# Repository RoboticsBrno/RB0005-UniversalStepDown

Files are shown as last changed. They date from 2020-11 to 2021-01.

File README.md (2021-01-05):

# RB0005 – Universal Stepdown

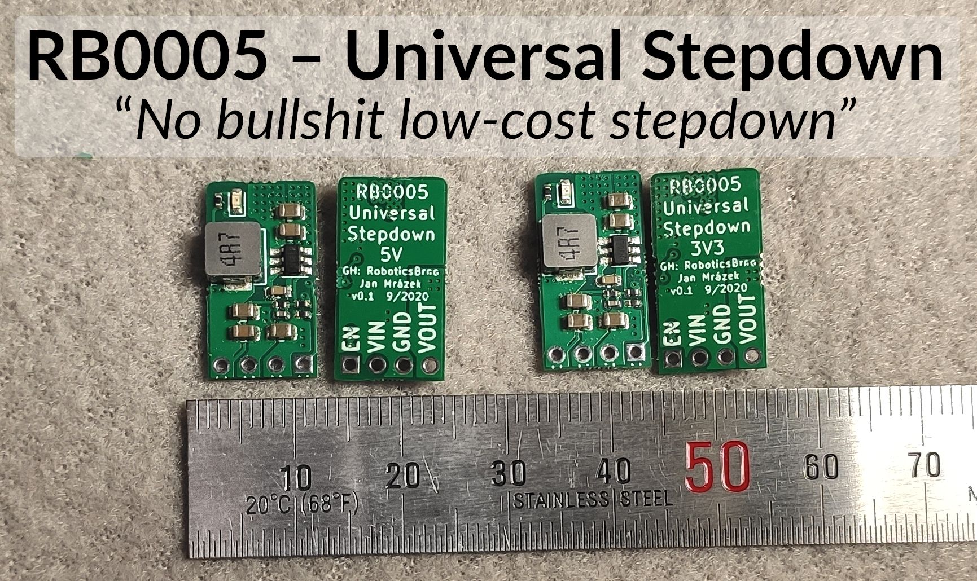
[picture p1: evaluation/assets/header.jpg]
StepDown photo




Most of our projects at RoboticsBrno are powered either by Li-ion cells or 12V
power sources. However, most of our servos and boards require either 5V or 3V3
power source.

We used to buy cheap stepdown modules from Aliexpress to do the job. They are
inexpensive but their performance is questionable. Also, it is always a
surprise what you get in the envelope – some batches of them operate better,
some of them worse. One day, we decided to stop wasting our time with
poor-performing modules and we designed our own custom module – the RB0005
Universal Stepdown.

It is a simple and low-cost design based on the
[SY8105](https://file.remont-aud.net/baza/dc_dc/data/SY8105.pdf). And it gets
the job done – see the evaluation of our design below. You can also look at our
design on the [project
repository](https://github.com/RoboticsBrno/RB0005-UniversalStepDown).

## What does the module offer?

- there are two versions – 5V and 3.3V fixed output
- input voltage up to 18 V
- continuous load: 3 A (without cooling)/4 A (with cooling)
- pin compatible with 7805 linear voltage regulator and most of the Chinese modules
- has an enable pin (pull low to disable the module)
- small factor 10.5×19.5 mm
- low price: ~3 USD
- you know what to expect – we provide measurements of the module performance
    - **see the performance of [the 5V version](https://roboticsbrno.github.io/RB0005-UniversalStepDown/eval5v/index.html)**
    - **see the performance of [the 3V3 version](https://roboticsbrno.github.io/RB0005-UniversalStepDown/eval3v/index.html)**
    - **see the performance of [the 5V version v2](https://roboticsbrno.github.io/RB0005-UniversalStepDown/eval5v_v2)**

## What we do not provide?

- high-end, precision solution
    - we do not focus on incredibly high module efficiency
    - we do not focus on being low-noise

## FAQ

#### Why the "RB0005" prefix?

To quickly distinguish our projects at
[RoboticsBrno](https://github.com/RoboticsBrno/), e.g., when ordering, we
decided to give a each project a unique code.

#### Why is there no adjustable version?

We aim for usability. Usually, you need to lower your voltage to 5 V (servos) or
3.3 V (powering MCU) in DIY robotics. Having an adjustable version increases
the chances of misconfiguration.

#### Why should I use your module instead of $1 module from Aliexpress?

Well, it depends on your needs. If you need a certain level of reliability, it
might be beneficial to know what to expect from your device. With our stepdown,
you know it: see [evaluation of the 5V
version](https://roboticsbrno.github.io/RB0005-UniversalStepDown/eval5v/index.html)
or the [the 3V3
version](https://roboticsbrno.github.io/RB0005-UniversalStepDown/eval3v/index.html).
You could buy a module from Aliexpress and measure it by yourself. However, that
is laborious and you cannot be sure that you will get the same-performing module
when you order it again.

## Licence

[RB0005 – Universal
Stepdown](https://roboticsbrno.github.io/RB0005-UniversalStepDown/) by [Jan
Mrázek](https://honzamrazek.cz) is licensed under [CC BY-NC-SA
4.0 ](https://creativecommons.org/licenses/by-nc-sa/4.0).

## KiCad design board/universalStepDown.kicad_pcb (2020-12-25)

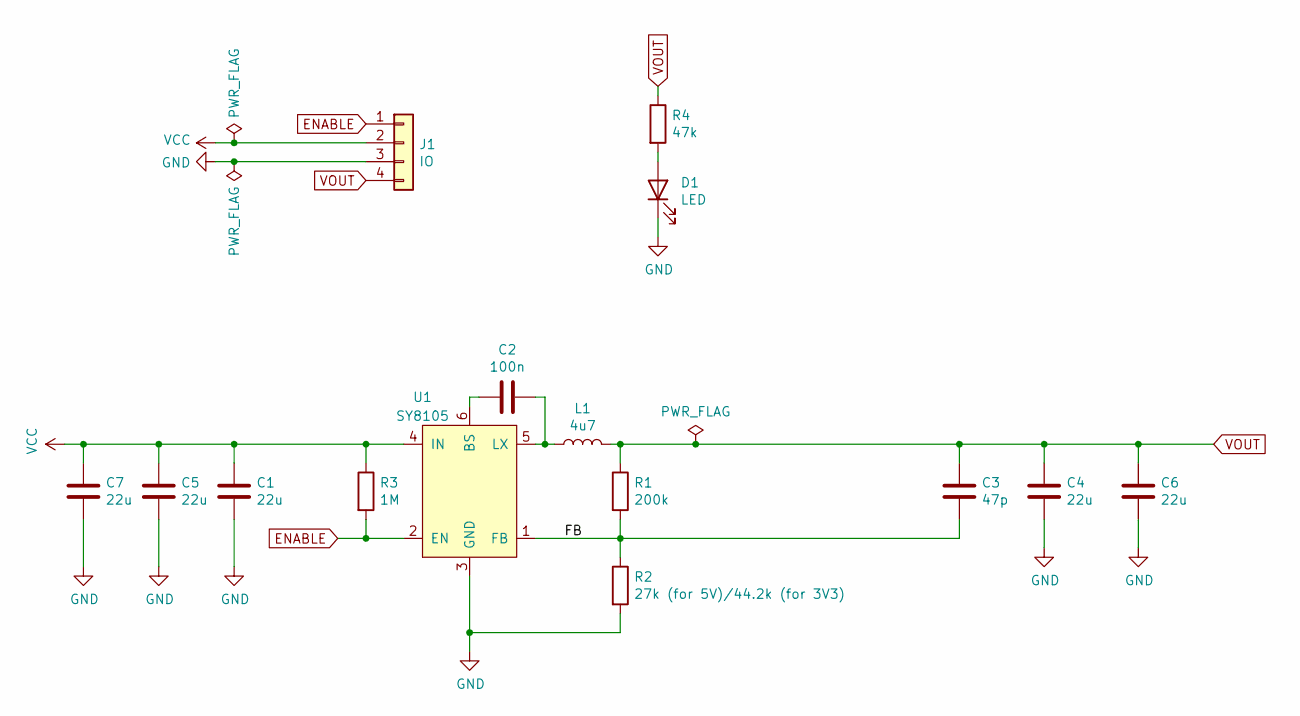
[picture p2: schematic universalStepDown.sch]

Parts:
C1, C4, C5, C6, C7: 22u; C_0805_2012Metric; LCSC C45783
C2: 100n; C_0603_1608Metric; LCSC C14663
C3: 47p; C_0402_1005Metric; LCSC C1567
D1: LED; LED_0603_1608Metric; LCSC C2286
J1: IO; PinHeader_1x04_P2.54mm_Horizontal
L1: 4u7; MWSA0503S; LCSC C408410
R1: 200k; R_0402_1005Metric; LCSC C25764
R2: 27k (for 5V)/44.2k (for 3V3); R_0402_1005Metric; LCSC_5V C25771
R3: 1M; R_0402_1005Metric; LCSC C26083
R4: 47k; R_0402_1005Metric; LCSC C25792
U1: SY8105; TSOT-23-6; LCSC C178247

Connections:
/FB: C3.1, R1.2, R2.1, U1.1 (FB)
ENABLE: J1.1, R3.2, U1.2 (EN)
GND: C1.2, C4.1, C5.2, C6.1, C7.2, D1.1 (K), J1.3, R2.2, U1.3 (GND)
unnamed: C2.1, L1.1, U1.5 (LX)
unnamed: C2.2, U1.6 (BS)
unnamed: D1.2 (A), R4.2
VCC: C1.1, C5.1, C7.1, J1.2, R3.1, U1.4 (IN)
VOUT: C3.2, C4.2, C6.2, J1.4, L1.2, R1.1, R4.1

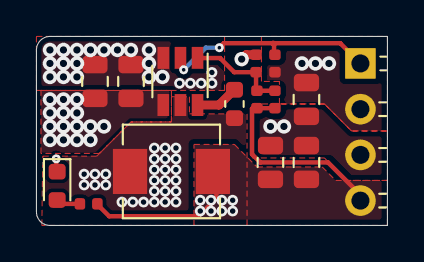
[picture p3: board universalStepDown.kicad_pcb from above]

Board: 4 copper layers, 19.5 x 10.5 mm, 15 parts (0 on the bottom side), 8 nets.

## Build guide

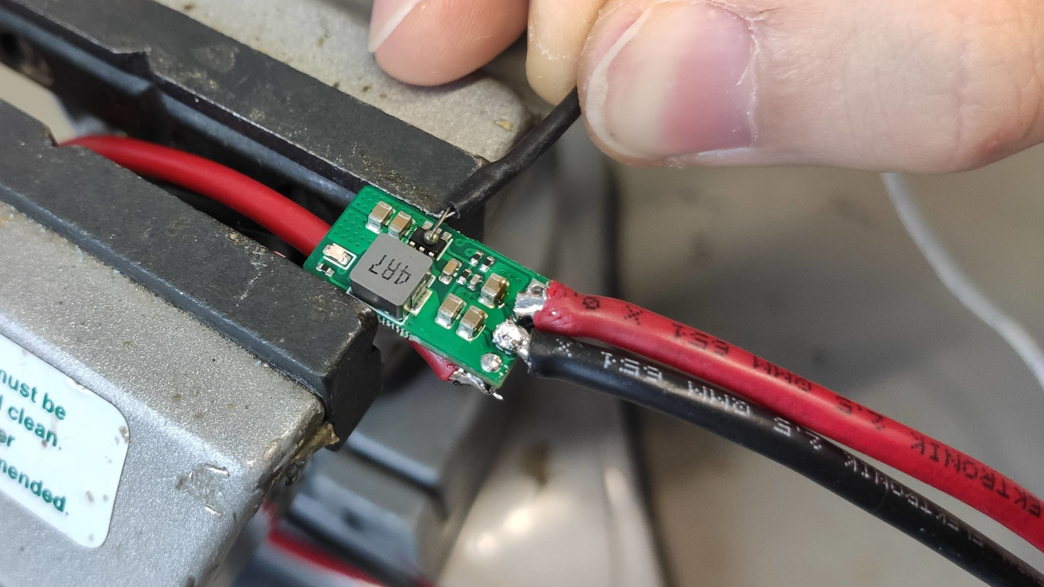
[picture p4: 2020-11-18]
evaluation/assets/setup2.jpg

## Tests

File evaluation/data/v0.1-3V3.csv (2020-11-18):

Input voltage @ V | Load @ A | Input current @ A | Output voltage @ V | Coil temperature after 5 minutes @ °C | Chip temperature after 5 minutes @ °C | Scope image | Noise - Vpp @ mV
14 | 0.1 | 0.03 | 3.321 | 25 | 23 | v0.1-3V3-1.png | 40
14 | 0.5 | 0.13 | 3.317 | 29 | 28 | v0.1-3V3-2.png | 40
14 | 1 | 0.26 | 3.316 | 32 | 30 | v0.1-3V3-3.png | 30
14 | 2 | 0.51 | 3.317 | 39 | 36 | v0.1-3V3-4.png | 70
14 | 3 | 0.79 | 3.291 | 60 | 48 | v0.1-3V3-5.png | 100
14 | 4 | 1.01 | 3.016 | 91 | 80 | v0.1-3V3-6.png | 90
7.4 | 0.1 | 0.05 | 3.32 | 24 | 23 | v0.1-3V3-7.png | 40
7.4 | 0.5 | 0.24 | 3.32 | 28 | 27 | v0.1-3V3-8.png | 50
7.4 | 1 | 0.47 | 3.31 | 30 | 29 | v0.1-3V3-9.png | 50
7.4 | 2 | 0.96 | 3.32 | 37 | 33 | v0.1-3V3-10.png | 70
7.4 | 3 | 1.49 | 3.32 | 52 | 43 | v0.1-3V3-11.png | 90
7.4 | 4 | 1.96 | 3.156 | 77 | 62 | v0.1-3V3-12.png | 90
4.2 | 0.1 | 0.08 | 3.312 | 25 | 25 | v0.1-3V3-13.png | 40
4.2 | 0.5 | 0.4 | 3.31 | 26 | 26 | v0.1-3V3-14.png | 30
4.2 | 1 | 0.81 | 3.315 | 27 | 26 | v0.1-3V3-15.png | 30
4.2 | 2 | 1.69 | 3.323 | 34 | 29 | v0.1-3V3-16.png | 50
4.2 | 3 | 2.67 | 3.332 | 51 | 41 | v0.1-3V3-17.png | 70
4.2 | 4 | 3.56 | 3.13 | 78 | 66 | v0.1-3V3-18.png | 70

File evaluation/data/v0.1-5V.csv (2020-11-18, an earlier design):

Input voltage @ V | Load @ A | Input current @ A | Output voltage @ V | Coil temperature after 5 minutes @ °C | Chip temperature after 5 minutes @ °C | Scope image | Noise - Vpp @ mV
14 | 0.1 | 0.04 | 5.03 | 23 | 22 | v0.1-5V-1.png | 80
14 | 0.5 | 0.19 | 5.025 | 28 | 26 | v0.1-5V-2.png | 50
14 | 1 | 0.38 | 5.029 | 35 | 31 | v0.1-5V-3.png | 90
14 | 2 | 0.77 | 5.03 | 45 | 40 | v0.1-5V-4.png | 110
14 | 3 | 1.16 | 4.967 | 65 | 50 | v0.1-5V-5.png | 140
14 | 4 | 1.5 | 4.743 | 93 | 83 | v0.1-5V-6.png | 70
7.4 | 0.1 | 0.07 | 5.03 | 23 | 22 | v0.1-5V-7.png | 60
7.4 | 0.5 | 0.35 | 5.027 | 26 | 24 | v0.1-5V-8.png | 60
7.4 | 1 | 0.7 | 5.031 | 29 | 28 | v0.1-5V-9.png | 70
7.4 | 2 | 1.43 | 5.047 | 36 | 33 | v0.1-5V-10.png | 60
7.4 | 3 | 2.22 | 5.07 | 51 | 45 | v0.1-5V-11.png | 70
7.4 | 4 | 3.04 | 5.01 | 84 | 65 | v0.1-5V-12.png | 80

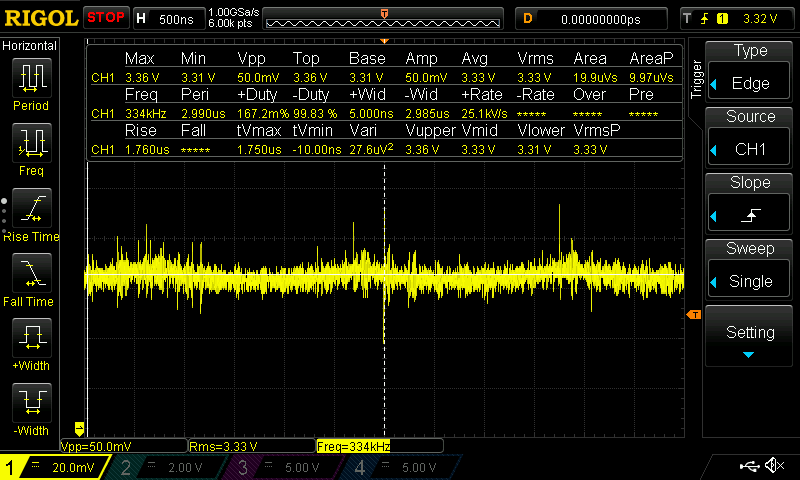
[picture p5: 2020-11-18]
evaluation/assets/waveforms/v0.1-3V3-16.png

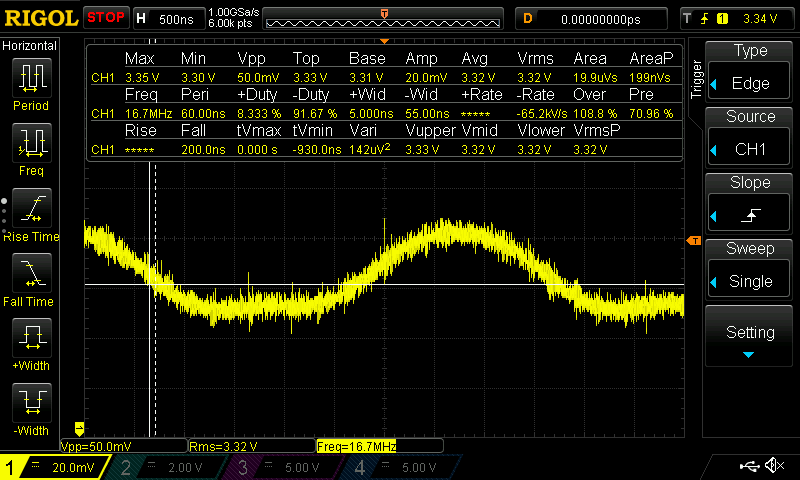
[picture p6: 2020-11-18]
evaluation/assets/waveforms/v0.1-3V3-9.png

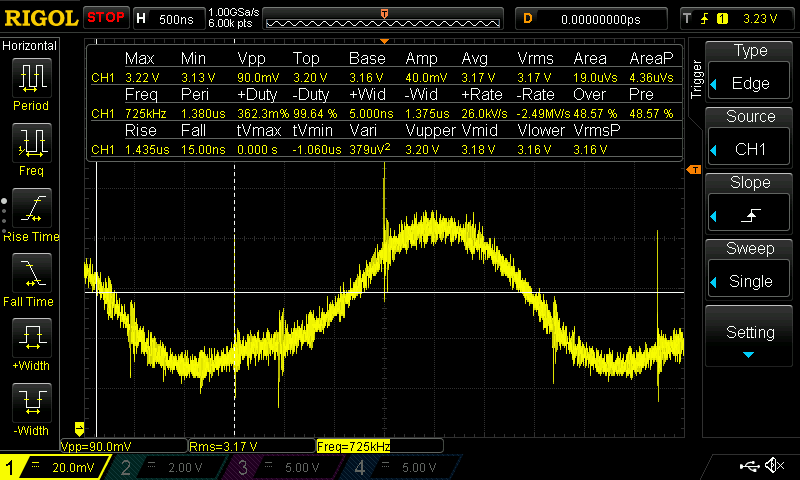
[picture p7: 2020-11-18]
evaluation/assets/waveforms/v0.1-3V3-12.png

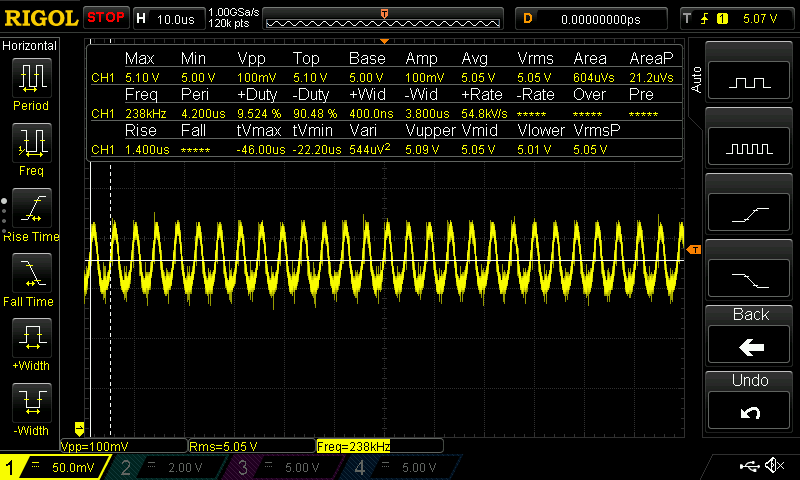
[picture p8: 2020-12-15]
evaluation/assets/waveforms/v0.2-5V-9.png

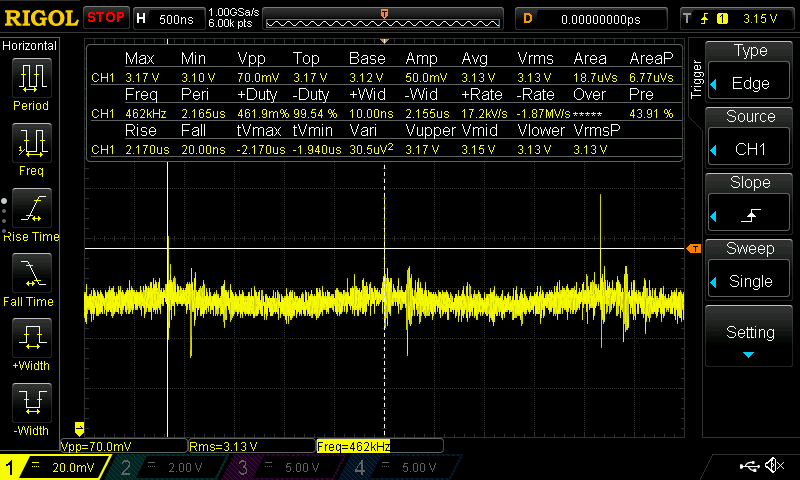
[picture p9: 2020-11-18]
evaluation/assets/waveforms/v0.1-3V3-18.png

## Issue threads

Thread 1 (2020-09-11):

C2 voltage rating

cednik, 2020-09-11:
C2 should be at least for 25 V.
I suggest 100 nF @ 50 V 0603 [C14663](https://lcsc.com/product-detail/Multilayer-Ceramic-Capacitors-MLCC-SMD-SMT_100nF-104-10-50V_C14663.html/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).

yaqwsx, 2020-09-14:
Resolved in 60372b8f240a20923353d0b3388f130479edcc53

Closed 2020-09-14.

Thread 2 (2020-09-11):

Enable pull-p value

cednik, 2020-09-11:
I suggest use 1M resistor [C26083](https://lcsc.com/product-detail/Chip-Resistor-Surface-Mount_Uniroyal-Elec-0402WGF1004TCE_C26083.html/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).

yaqwsx, 2020-09-14:
Resolved in 60372b8f240a20923353d0b3388f130479edcc53

Closed 2020-09-14.

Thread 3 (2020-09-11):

Enable trace layer

cednik, 2020-09-11:
Move Enable signal from bottorm to in1 layer (segment under IC).

yaqwsx, 2020-09-14:
Resolved in 60372b8f240a20923353d0b3388f130479edcc53

Closed 2020-09-14.

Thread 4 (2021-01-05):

Wrong link

PexMor, 2021-01-05:
Hello Honza,

I just have spotted that the link to 5V v2 eval is wrong:

now it is:
https://roboticsbrno.github.io/RB0005-UniversalStepDown/eval5v/eval5v_v2

but this actually work:
https://roboticsbrno.github.io/RB0005-UniversalStepDown/eval5v_v2

Can you have a look and eventually fix it :-)
Petr

yaqwsx, 2021-01-05:
Thank you for noting, Peter! I fixed the link in 6bc64e2.

Closed 2021-01-28.

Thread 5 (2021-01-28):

Query regarding Cin caps

solarmon, 2021-01-28:
Hi.

In the 12v to 5V v2 design, there are 3 x 22uF input caps.

But in the SY8105 data sheet:

https://datasheet.lcsc.com/szlcsc/1810010130_Silergy-Corp-SY8105ADC_C178247.pdf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

The application diagram only shows 1 x 10uF cap. Although, further down in the notes for CIN, it also suggests having a 100nF cap in parallel with the 10uF cap.

Can you explain the benefits of this design with three 22uF input caps versus what is recommended in the SY8105 data sheet.

yaqwsx, 2021-01-28:
Usage for 3x 22uF caps basically came up from our experiments with the chip - it better reacts to pulse loads compared to the value in the datasheet (especially for RC servos). Also, the step-down is designed for hacky/dirty usage where the users often use long input leads and do not supply the stepdown with an additional electrolytic capacitor.

The 100 nF capacitor is missing as it makes no difference in our experience; often a single large ceramic capacitor performs similarly; you can read more about it in [this thread](https://twitter.com/BenKrasnow/status/1084196370267856896) with Ben Krasnow from Applied science - there are some interesting papers and slides listed.

solarmon, 2021-01-28:
Thanks for the quick response.

I'm looking to use the circuit design to power 5V floppy drives, so the use case is not the same compared to the intended use. Although, the the floppy drives do have a step motor in them.

I suspect I could get away with using just a single 10uF cap for my use case.

yaqwsx, 2021-01-28:
I think a 10uF cap should work fine for you.

Closed 2021-01-29.

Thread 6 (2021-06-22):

SY8105 source and availability

solarmon, 2021-06-22:
Hi,

I've been using this SY8105 based regulator circuit in my projects with great success. However, I'm now having trouble sourcing the SY8105 regulator IC.

LCSC doesn't have them in stock any longer. And RS, Farnell, Mouser, don't seem to stock them. eBay prices are ridiculous.

Can you advise on a suitable source for bulk order. Or if there is a suitable drop in replacement.

yaqwsx, 2021-06-23:
Hi! Unfortunately, I have no direct replacement. At the time of designing, SY8105 was easily available (I used it in a few other designs for quite some time). I am afraid, that the current global chip shortage has affected this.

How many pieces do you need?

solarmon, 2021-06-23:
Luckily, I still have some left from my last order of 100 pieces. But this is about others who need to find the parts to build the project that uses it.

If I can't find a suitable source to recommend then I might have to find another solution. I had updated my project to use the RB0005 board as a modular option, but then realised the issue when I went to look at the availability for SY8105 with a view to building the boards myself. But I might have to think about supporting other commonly available regulator boards that can be found on eBay, Aliexpress, etc.

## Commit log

2020-09-07 Add initial version
    [universalStepDown.kicad_pcb, universalStepDown.sch]
2020-09-13 Fix issues by cednik, prepare multi-voltage variant
    [universalStepDown.kicad_pcb, universalStepDown.sch]
2020-09-14 Prepare Makefile
    [universalStepDown.kicad_pcb, universalStepDown.sch]
2020-11-18 Prepare presentation
    [v0.1-3V3.csv, v0.1-5V.csv]
2020-12-15 Add evaluation of v0.2
    [v0.2-5V.csv]
2020-12-25 Improve thermal design
    [universalStepDown.kicad_pcb]
2020-12-25 Tweak label position
    [universalStepDown.kicad_pcb]
2021-01-05 Fix typo in evaluation
    [v0.2-5V.csv]
